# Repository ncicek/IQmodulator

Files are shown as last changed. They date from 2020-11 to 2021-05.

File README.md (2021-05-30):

# IQmodulator

A low cost FPGA-based platform for generating RF signals.
It is implemented with more discrete components than a typical SDR with an "all in one" RF transceiver chip. For example the quadrature double-balanced mixer uses hand-wound trifilar transformers.
 As such, it is intended as a learning platform to show the individual components at play.

# Description
The board is designed to plug into the Lattice MachXO3 FPGA starter board.
The FPGA generates the 10-bit baseband I and Q signals. A MAX5853 DAC generates the baseband analog signals which are filtered with a differential 7th order chebyshev. The FPGA PLL is also used to synthesize the quadrature LO which goes to the quadrature mixer in order to upconvert the baseband up to high frequency.

The RTL uses wishbone modules which are heavily based on material from [Gisselquist Technology's blog posts and sample code](https://zipcpu.com).

# PCB:
Photo of the IQModulator board

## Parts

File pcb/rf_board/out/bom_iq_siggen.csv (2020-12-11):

Comment | Designator | Footprint | LCSC Part Number
3p | C1 | Capacitor_SMD:C_0603_1608Metric
DNI | C12,C13 | Capacitor_SMD:C_0603_1608Metric
0.1u | C16,C17,C18,C19,C20,C21,C30,C38,C41,C42,C43,C44,C48,C49,C51,C52,C53,C54,C55,C56,C57,C58 | Capacitor_SMD:C_0603_1608Metric | C14663
4.7p | C14,C15,C22,C23,C36,C37,C39,C40 | Capacitor_SMD:C_0603_1608Metric | C1669
220u 25V tantalum | C28 | Capacitor_Tantalum_SMD:CP_EIA-7343-43_Kemet-X_Pad2.25x2.55mm_HandSolder | C7231
220u tantalum 25V | C31,C33 | Capacitor_Tantalum_SMD:CP_EIA-7343-43_Kemet-X_Pad2.25x2.55mm_HandSolder | C7231
DNI - Feedforward cap | C35 | Capacitor_SMD:C_0805_2012Metric_Pad1.15x1.40mm_HandSolder
10n | C5 | Capacitor_SMD:C_0603_1608Metric | C57112
220u | C6 | Capacitor_Tantalum_SMD:CP_EIA-7343-43_Kemet-X_Pad2.25x2.55mm_HandSolder | C7231
680p | C71,C72,C83,C84 | Capacitor_SMD:C_0603_1608Metric | C30816
330p | C68,C76,C80,C88 | Capacitor_SMD:C_0603_1608Metric | C1664
10u | C2,C3,C4,C7,C8,C9,C24,C25,C26,C27,C29,C32,C34,C59,C60,C61,C62,C63,C64,C65 | Capacitor_SMD:C_0603_1608Metric | C19702
LED | D1,D2,D3,D4 | LED_SMD:LED_0805_2012Metric_Pad1.15x1.40mm_HandSolder | C34499
BAT15-04W | D5,D6,D7,D8 | Package_TO_SOT_SMD:SOT-323_SC-70_Handsoldering
MBRS540T3G | D9,D10,D11 | Diode_SMD:D_SMB_Handsoldering | C14651
Ferrite_Bead_Small | FB1,FB2,FB3,FB4,FB5,FB6,FB7,FB8,FB9 | Inductor_SMD:L_0805_2012Metric_Pad1.05x1.20mm_HandSolder | C19330
J3 - BANK0 | J1 | Connector_PinHeader_2.54mm:PinHeader_2x20_P2.54mm_Vertical
Barrel_Jack | J10 | Connector_BarrelJack:BarrelJack_Horizontal
Conn_Coaxial | J6,J7,J8,J9,J11,J18,J19 | iq_siggen:SMA_Samtec_SMA-J-P-X-ST-EM1_EdgeMount_withSTEP
Conn_01x01_Male | J4,J12,J13,J14,J15,J16,J17 | Connector_PinHeader_2.54mm:PinHeader_1x01_P2.54mm_Vertical
J4 - BANK1 | J2 | Connector_PinHeader_2.54mm:PinHeader_2x20_P2.54mm_Vertical
Conn_01x20_Male | J3 | Connector_PinHeader_2.54mm:PinHeader_1x20_P2.54mm_Vertical
SolderJumper_3_Open | JP1,JP2,JP4,JP5 | iq_siggen:50ohm_solder_jumper
330n | L10,L12,L20,L23,L28,L30,L38,L41 | Inductor_SMD:L_0603_1608Metric | C46859
470n | L14,L17,L32,L35 | Inductor_SMD:L_0603_1608Metric | C21307
33u | L6 | Inductor_SMD:L_Bourns_SRR1260
3.3u | L7 | Inductor_THT:L_Axial_L9.5mm_D4.0mm_P12.70mm_Horizontal_Fastron_SMCC
6.8k - optional output termination | R100 | Resistor_SMD:R_0603_1608Metric
1.985k | R101 | Resistor_SMD:R_0603_1608Metric
22 | R17,R18,R19,R21,R22,R23,R24,R25,R26,R27,R28,R29,R34,R36,R37,R38,R39,R40,R41,R42,R43,R44,R45,R52,R53 | Resistor_SMD:R_0603_1608Metric | C23345
3k | R48,R49,R86 | Resistor_SMD:R_0603_1608Metric | C4211
DNI | R46,R47,R54,R55,R66,R68 | Resistor_SMD:R_0603_1608Metric
220 | R56,R57,R58,R59 | Resistor_SMD:R_0603_1608Metric | C22962
0 | R2,R3,R4,R5,R6,R7,R10,R11,R12,R13,R14,R15,R16,R30,R31,R32,R33,R67,R69 | Resistor_SMD:R_0603_1608Metric | C21189
16.5 | R62,R63,R64 | Resistor_SMD:R_0603_1608Metric | C12054
DNI-50 | R60,R61,R65,R82 | Resistor_SMD:R_0603_1608Metric
499 | R72,R73,R74,R75,R94,R95,R96,R97 | Resistor_SMD:R_0603_1608Metric | C23065
1.5k | R76,R77,R78,R79 | Resistor_SMD:R_0603_1608Metric | C22843
100 | R8,R70,R71 | Resistor_SMD:R_0603_1608Metric | C22775
49.9 | R80,R81,R92,R93,R104,R105 | Resistor_SMD:R_0603_1608Metric | C23185
DNI - 50 | R83 | Resistor_SMD:R_0603_1608Metric
47k | R84,R85 | Resistor_SMD:R_0603_1608Metric | C25819
1k | R87,R98,R99,R102,R103 | Resistor_SMD:R_0603_1608Metric | C21190
24.9 | R88,R89,R90,R91 | Resistor_SMD:R_0603_1608Metric | C22916
SW_Push | SW1,SW2 | Button_Switch_THT:SW_PUSH_6mm_H5mm
Transformer_1P_SS | T1,T2,T3,T4 | iq_siggen:trifilar_wound_toroidal_rf_transformer
TestPoint | TP1,TP4,TP10,TP17,TP18,TP19,TP22,TP23,TP24,TP25,TP30,TP31,TP32,TP33,TP34 | TestPoint:TestPoint_Pad_D1.5mm
TestPoint | TP51,TP52,TP53,TP56,TP57,TP58 | TestPoint:TestPoint_Pad_D1.0mm
AMS1117-3.3 | U1 | Package_TO_SOT_SMD:SOT-223-3_TabPin2 | C6186
TPS72325DBVR | U2 | Package_TO_SOT_SMD:SOT-23-5_HandSoldering | C69932
TLV73325PDBVT | U3 | Package_TO_SOT_SMD:SOT-23-5_HandSoldering
TLV3542IDR | U4,U7 | Package_SO:SOIC-8_3.9x4.9mm_P1.27mm
LM2596S-ADJ | U5 | Package_TO_SOT_SMD:TO-263-5_TabPin3
MAX5853ETL-T | U6 | iq_siggen:qfn_max5853

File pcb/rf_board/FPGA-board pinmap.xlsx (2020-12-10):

Connector | Pin number | Pin name | Net name
J4 | 24 | H15 | A0
J4 | 20 | J15 | A1
J4 | 17 | K15 | A2
J4 | 16 | K16 | A3
J4 | 15 | K14 | A4
J4 | 14 | L16 | A5
J4 | 10 | M16 | A6
J4 | 8 | N16 | A7
J4 | 7 | L14 | A8
J4 | 6 | N14 | A9
J4 | 39 | G14 | B0
J4 | 37 | D14 | B1
J4 | 38 | F14 | B2
J4 | 35 | D16 | B3
J4 | 34 | E14 | B4
J4 | 33 | E16 | B5
J4 | 30 | E15 | B6
J4 | 29 | F16 | B7
J4 | 28 | F15 | B8
J4 | 26 | G15 | B9
J3 | 10 | D10 | DAC_CLK_P
J3 | 9 | E10 | DAC_CLK_N
J3 | 30 | B9 | I_CLK_P
J3 | 27 | A10 | I_CLK_N
J3 | 18 | D8 | Q_CLK_P
J3 | 16 | E9 | Q_CLK_N
J4 | 5 | M14 | ~CW
J4 | 25 | H16 | CLK_EXT_IN
J4 | 19 | H14 | CLK_OUT
J3 | 13 | f9 | LED0
J3 | 15 | e8 | LED1
J3 | 17 | e7 | LED2
J3 | 19 | d7 | LED3
J3 | 5 | F8 | SW0
J3 | 6 | B12 | SW1

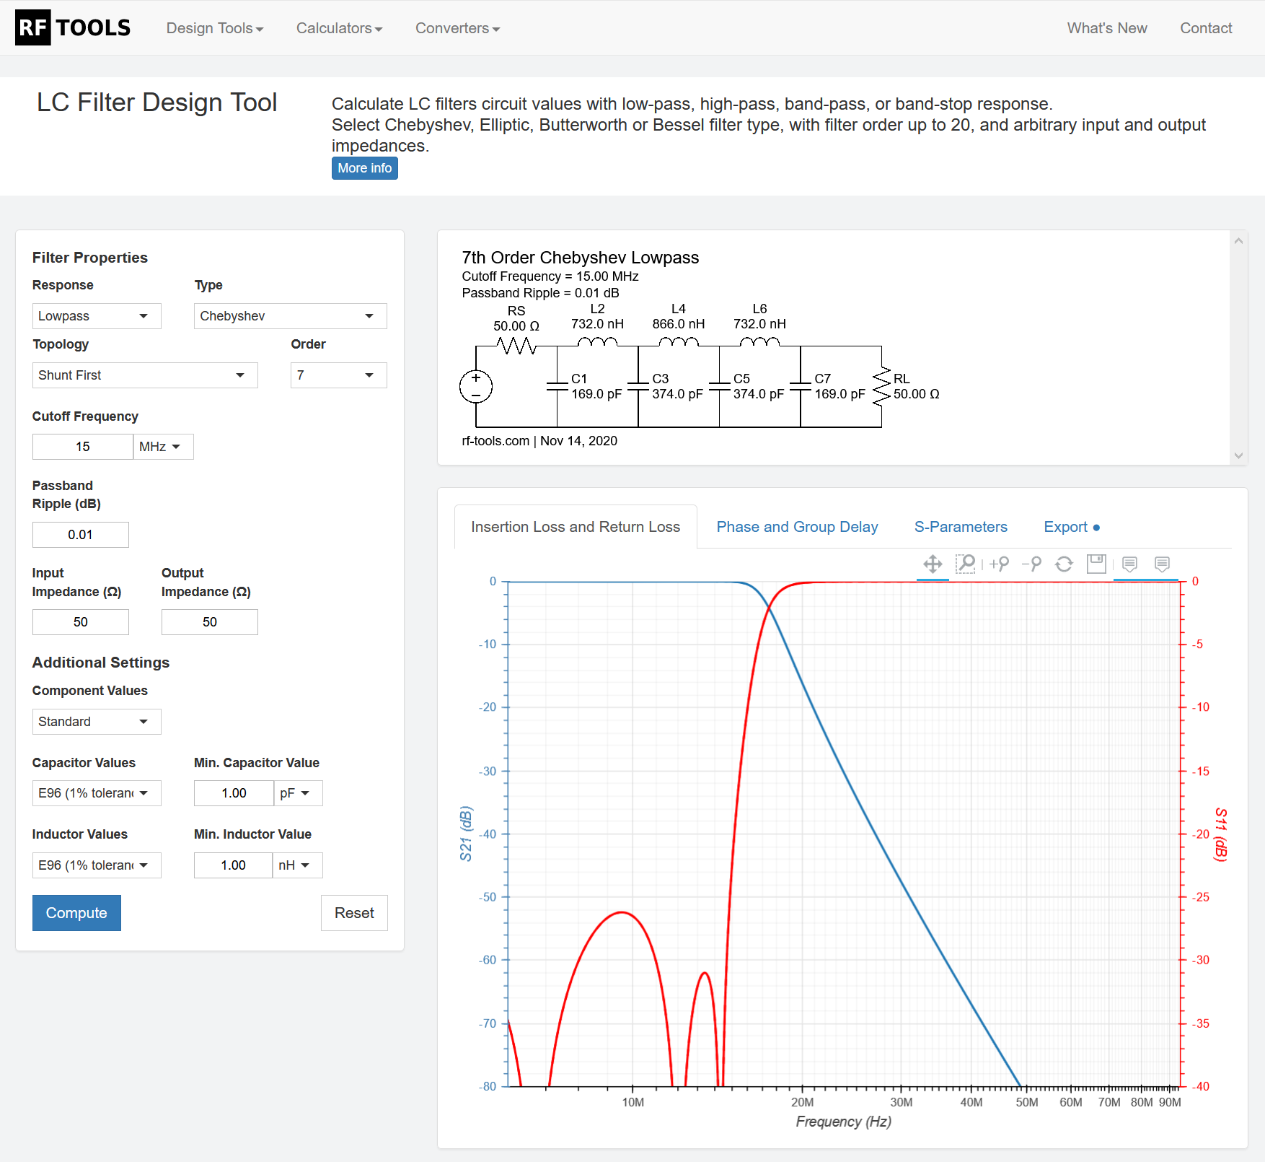
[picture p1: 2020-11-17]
pcb/rf_board/7th order chebyshev 15MHz AA LPF.PNG

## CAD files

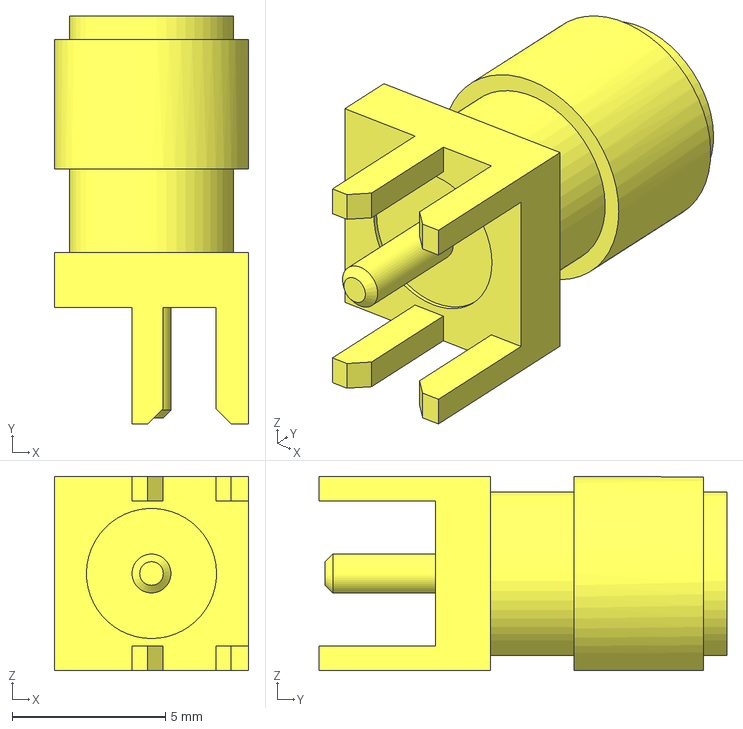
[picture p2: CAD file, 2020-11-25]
pcb/rf_board/SMA-J-P-H-ST-EM1--3DModel-STEP-46669.STEP
6.35 x 13.3 x 6.35 mm

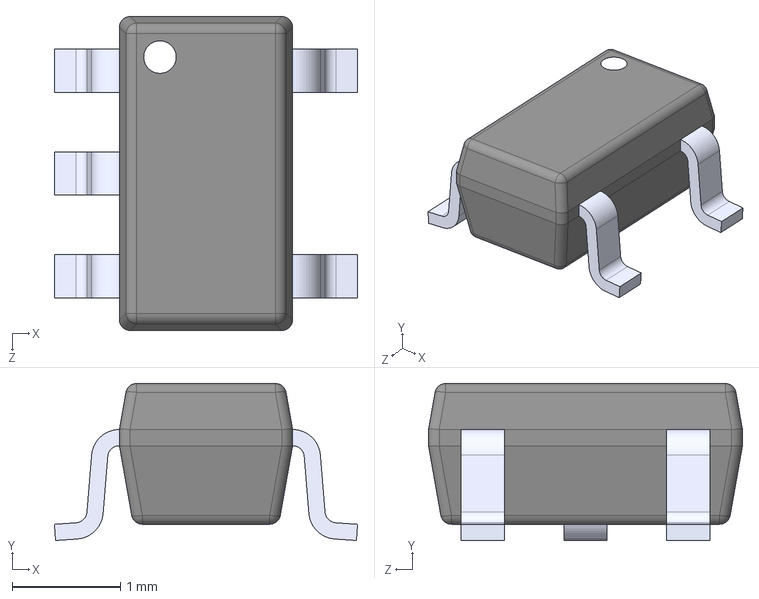
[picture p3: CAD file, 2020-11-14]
pcb/rf_board/TLV73325PDBVT.step
2.80 x 1.45 x 2.90 mm

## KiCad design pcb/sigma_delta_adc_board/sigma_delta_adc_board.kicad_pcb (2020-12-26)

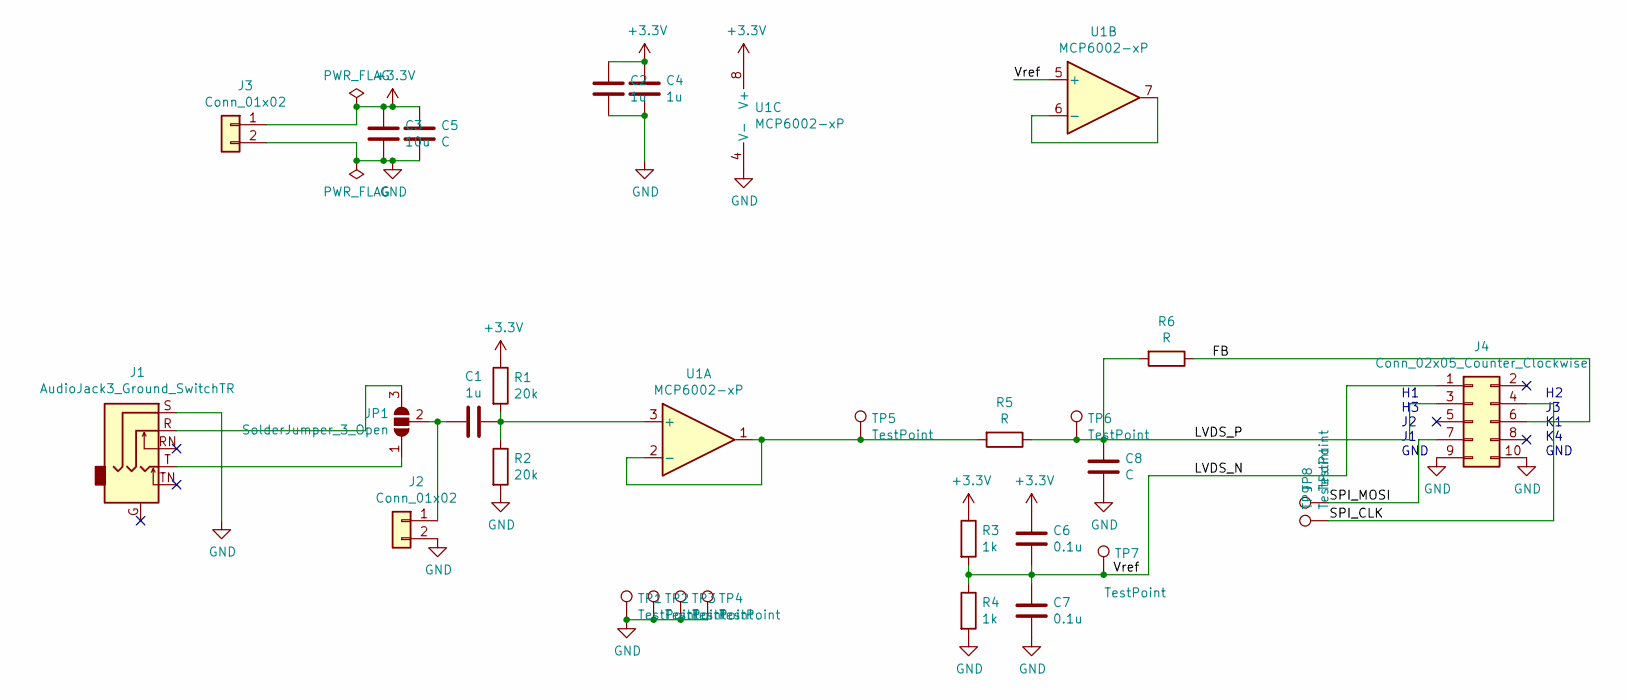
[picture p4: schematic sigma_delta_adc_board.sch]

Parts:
C1: 1u; C_Disc_D5.0mm_W2.5mm_P5.00mm
C2, C4: 1u; C_0805_2012Metric_Pad1.18x1.45mm_HandSolder
C3: 10u; C_Disc_D5.0mm_W2.5mm_P5.00mm
C5: C; C_Disc_D5.0mm_W2.5mm_P5.00mm
C6, C7: 0.1u; C_0805_2012Metric_Pad1.18x1.45mm_HandSolder
C8: C; C_0805_2012Metric_Pad1.18x1.45mm_HandSolder
J1: AudioJack3_Ground_SwitchTR; STX-3120-5B
J2, J3: Conn_01x02; PinHeader_1x02_P2.54mm_Vertical
J4: Conn_02x05_Counter_Clockwise; PinSocket_2x05_P2.54mm_Vertical
JP1: SolderJumper_3_Open; SolderJumper-3_P1.3mm_Open_RoundedPad1.0x1.5mm_NumberLabels
R1, R2: 20k; R_0805_2012Metric_Pad1.20x1.40mm_HandSolder
R3, R4: 1k; R_0805_2012Metric_Pad1.20x1.40mm_HandSolder
R5, R6: R; R_0805_2012Metric_Pad1.20x1.40mm_HandSolder
TP1, TP2, TP3, TP4, TP5, TP6, TP7: TestPoint; PinHeader_1x01_P2.54mm_Vertical
TP8, TP9: TestPoint; TestPoint_Pad_D1.0mm
U1: MCP6002-xP; DIP-8_W7.62mm

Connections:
+3V3: C2.2, C3.1, C4.2, C5.1, C6.2, J3.1, R1.1, R3.1, U1.8 (V+)
/FB: J4.6, R6.1
/LVDS_N: C6.1, C7.2, J4.1, R3.2, R4.1, TP7.1, U1.5 (+)
/LVDS_P: C8.2, J4.3, R5.1, R6.2, TP6.1
/SPI_CLK: J4.4, TP9.1
/SPI_MOSI: J4.7, TP8.1
GND: C2.1, C3.2, C4.1, C5.2, C7.1, C8.1, J1.S, J2.2, J3.2, J4.9, J4.10, R2.2, R4.2, TP1.1, TP2.1, TP3.1, TP4.1, U1.4 (V-)
unnamed: C1.1, R1.2, R2.1, U1.3 (+)
unnamed: C1.2, J2.1, JP1.2 (C)
unnamed: J1.R, JP1.3 (B)
unnamed: J1.T, JP1.1 (A)
unnamed: R5.2, TP5.1, U1.1, U1.2 (-)
unnamed: U1.6 (-), U1.7

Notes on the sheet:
H1 H3 J2 J1 GND
H2 J3 K1 K4 GND

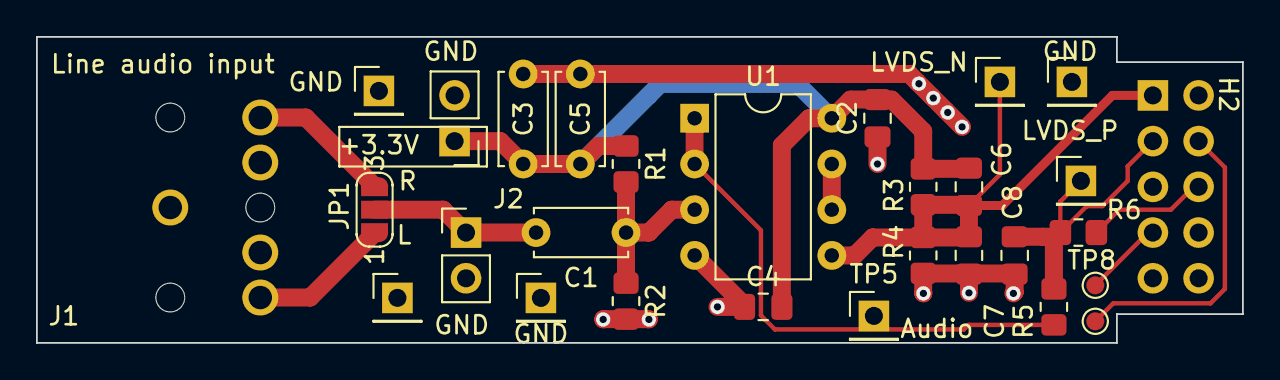
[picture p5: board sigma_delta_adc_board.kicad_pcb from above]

Board: 2 copper layers, 67.0 x 17.0 mm, 29 parts (1 on the bottom side), 13 nets.

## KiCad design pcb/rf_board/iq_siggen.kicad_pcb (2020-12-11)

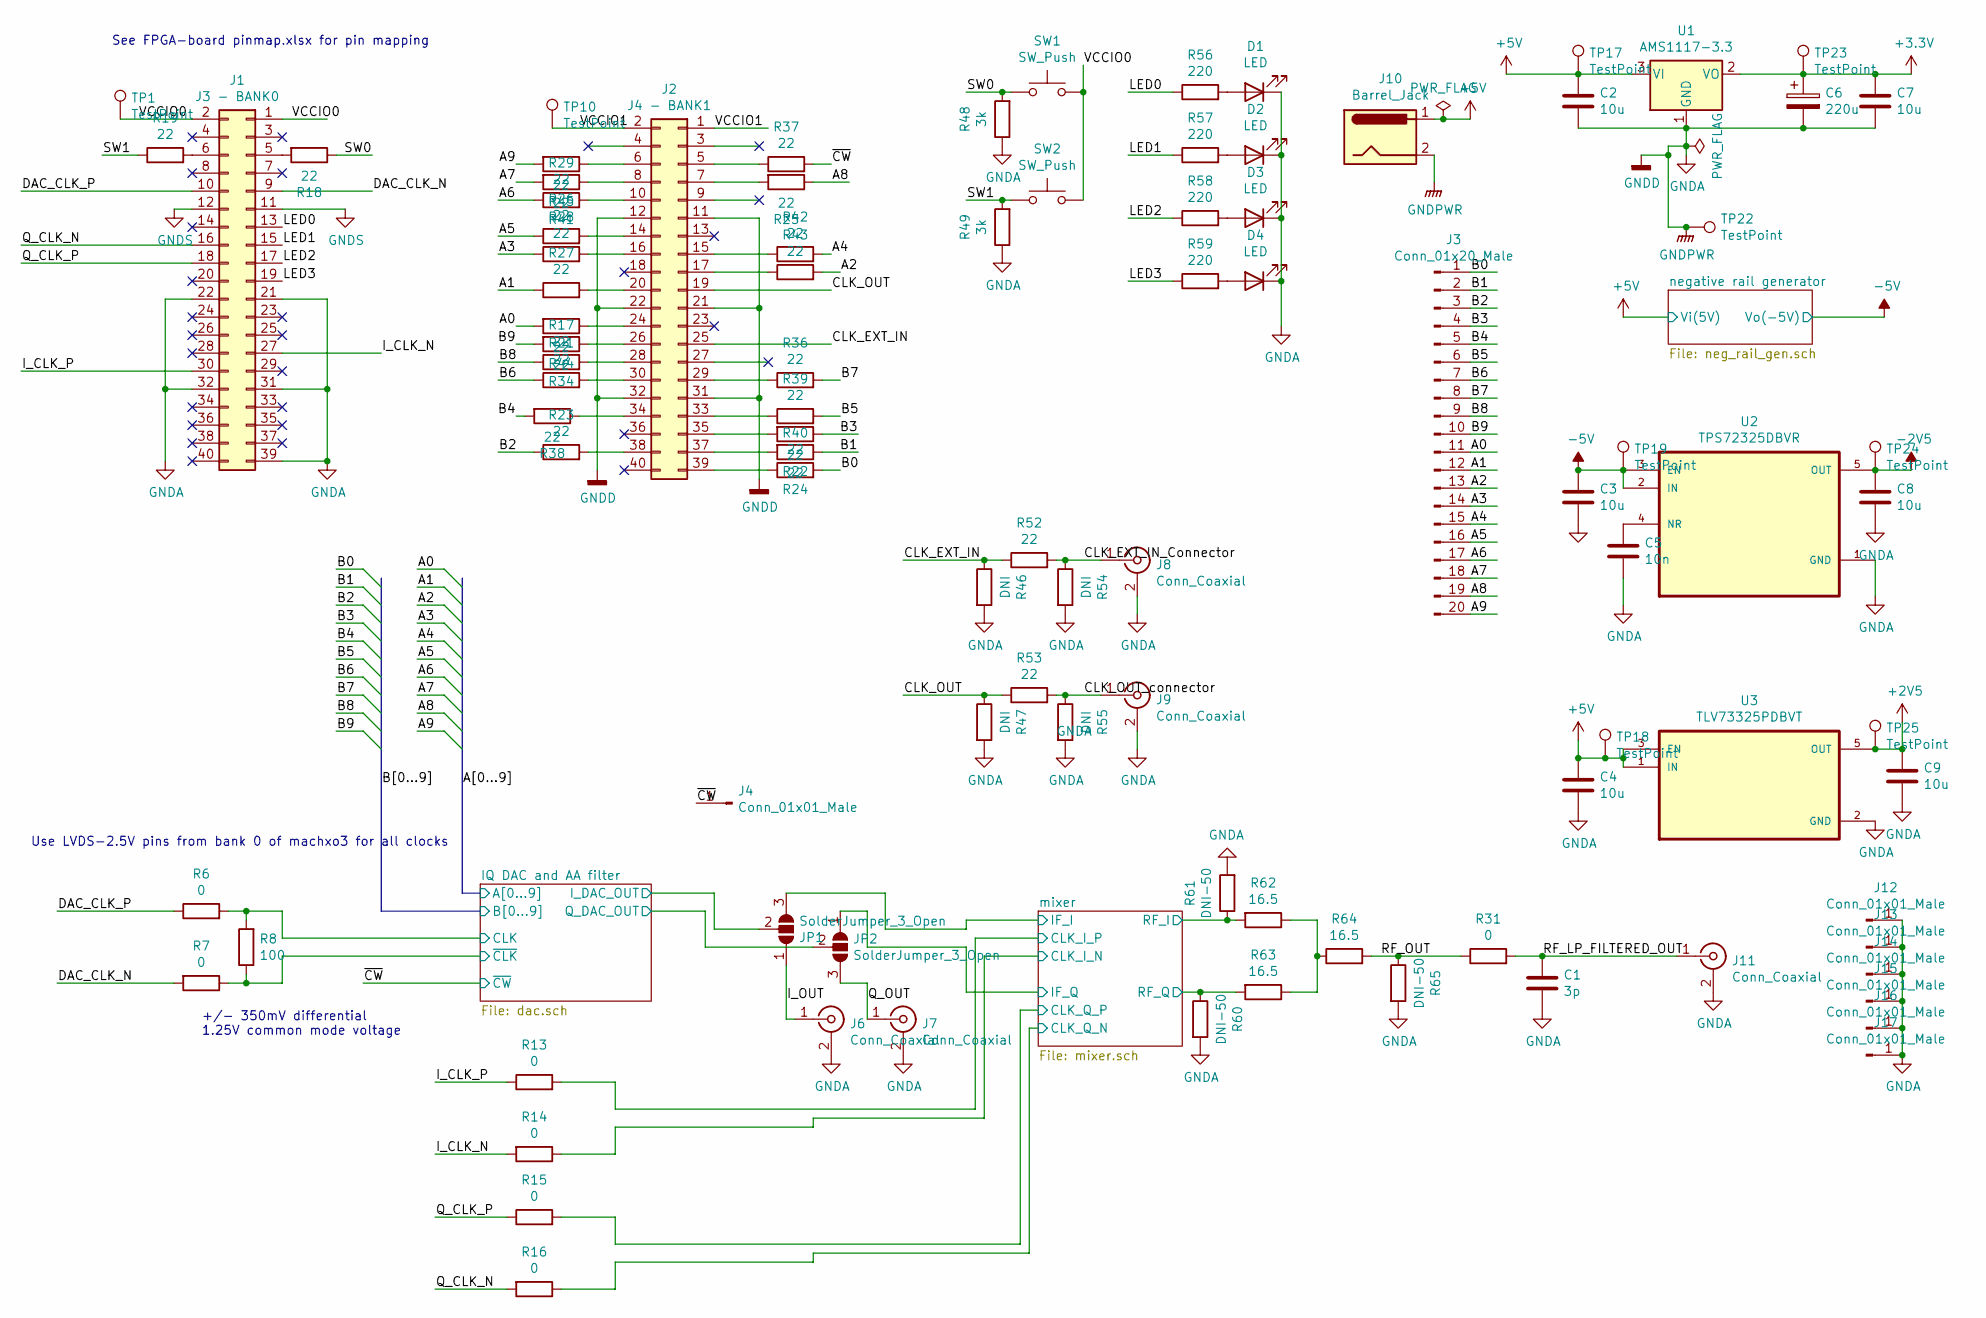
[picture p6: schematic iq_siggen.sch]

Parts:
C1: 3p; C_0603_1608Metric
C2, C3, C4, C7, C8, C9: 10u; C_0603_1608Metric; LCSC C19702
C5: 10n; C_0603_1608Metric; LCSC C57112
C6: 220u; CP_EIA-7343-43_Kemet-X_Pad2.25x2.55mm_HandSolder; LCSC C7231
D1, D2, D3, D4: LED; LED_0805_2012Metric_Pad1.15x1.40mm_HandSolder; LCSC C34499
J1: J3 - BANK0; PinHeader_2x20_P2.54mm_Vertical
J2: J4 - BANK1; PinHeader_2x20_P2.54mm_Vertical
J3: Conn_01x20_Male; PinHeader_1x20_P2.54mm_Vertical
J4, J12, J13, J14, J15, J16, J17: Conn_01x01_Male; PinHeader_1x01_P2.54mm_Vertical
J6, J7, J8, J9, J11: Conn_Coaxial; SMA_Samtec_SMA-J-P-X-ST-EM1_EdgeMount_withSTEP
J10: Barrel_Jack; BarrelJack_Horizontal
JP1, JP2: SolderJumper_3_Open; 50ohm_solder_jumper
R6, R7, R13, R14, R15, R16, R31: 0; R_0603_1608Metric; LCSC C21189
R8: 100; R_0603_1608Metric; LCSC C22775
R17, R18, R19, R21, R22, R23, R24, R25, R26, R27, R28, R29, R34, R36, R37, R38, R39, R40, R41, R42, R43, R44, R45, R52, R53: 22; R_0603_1608Metric; LCSC C23345
R46, R47, R54, R55: DNI; R_0603_1608Metric
R48, R49: 3k; R_0603_1608Metric; LCSC C4211
R56, R57, R58, R59: 220; R_0603_1608Metric; LCSC C22962
R60, R61, R65: DNI-50; R_0603_1608Metric
R62, R63, R64: 16.5; R_0603_1608Metric; LCSC C12054
SW1, SW2: SW_Push; SW_PUSH_6mm_H5mm
TP1, TP10, TP17, TP18, TP19, TP22, TP23, TP24, TP25: TestPoint; TestPoint_Pad_D1.5mm
U1: AMS1117-3.3; SOT-223-3_TabPin2; LCSC C6186
U2: TPS72325DBVR; SOT-23-5_HandSoldering; LCSC C69932
U3: TLV73325PDBVT; SOT-23-5_HandSoldering

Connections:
+2V5: C9.1, TP25.1, U3.5 (OUT); also elsewhere on the board
+3V3: C6.1, C7.1, TP23.1, U1.2 (VO); also elsewhere on the board
+5V: C2.1, C4.1, J10.1, TP17.1, TP18.1, U1.3 (VI), U3.1 (IN), U3.3 (EN); also elsewhere on the board
-2V5: C8.1, TP24.1, U2.5 (OUT); also elsewhere on the board
-5V: C3.1, TP19.1, U2.2 (IN), U2.3 (EN); also elsewhere on the board
/A0: J3.11, R44.2; also elsewhere on the board
/A1: J3.12, R27.1; also elsewhere on the board
/A2: J3.13, R43.2; also elsewhere on the board
/A3: J3.14, R28.1; also elsewhere on the board
/A4: J3.15, R42.2; also elsewhere on the board
/A5: J3.16, R26.1; also elsewhere on the board
/A6: J3.17, R29.1; also elsewhere on the board
/A7: J3.18, R41.2; also elsewhere on the board
/A8: J3.19, R25.1; also elsewhere on the board
/A9: J3.20, R45.2; also elsewhere on the board
/B0: J3.1, R40.2; also elsewhere on the board
/B1: J3.2, R24.1; also elsewhere on the board
/B2: J3.3, R23.1; also elsewhere on the board
/B3: J3.4, R22.1; also elsewhere on the board
/B4: J3.5, R38.2; also elsewhere on the board
/B5: J3.6, R39.2; also elsewhere on the board
/B6: J3.7, R21.1; also elsewhere on the board
/B7: J3.8, R36.2; also elsewhere on the board
/B8: J3.9, R17.1; also elsewhere on the board
/B9: J3.10, R34.2; also elsewhere on the board
/CLK_EXT_IN: J2.25, R46.1, R52.1
/CLK_EXT_IN_Connector: J8.1 (In), R52.2, R54.1
/CLK_OUT: J2.19, R47.1, R53.1
/CLK_OUT_connector: J9.1 (In), R53.2, R55.1
/DAC_CLK_N: J1.9, R7.2
/DAC_CLK_P: J1.10, R6.1
/IQ DAC and AA filter/CLK: R6.2, R8.2; also elsewhere on the board
/IQ DAC and AA filter/I_DAC_OUT: JP1.2 (C); also elsewhere on the board
/IQ DAC and AA filter/Q_DAC_OUT: JP2.2 (C); also elsewhere on the board
/IQ DAC and AA filter/~CLK: R7.1, R8.1; also elsewhere on the board
/I_CLK_N: J1.27, R14.2
/I_CLK_P: J1.30, R13.1
/I_OUT: J6.1 (In), JP1.1 (A)
/LED0: J1.13, R56.1
/LED1: J1.15, R57.1
/LED2: J1.17, R58.1
/LED3: J1.19, R59.1
/Q_CLK_N: J1.16, R16.2
/Q_CLK_P: J1.18, R15.1
/Q_OUT: J7.1 (In), JP2.3 (B)
/RF_LP_FILTERED_OUT: C1.1, J11.1 (In), R31.2
/RF_OUT: R31.1, R64.2, R65.1
/SW0: R18.1, R48.2, SW1.1
/SW1: R19.1, R49.2, SW2.1
/VCCIO0: J1.1, J1.2, SW1.2, SW2.2, TP1.1
/VCCIO1: J2.1, J2.2, TP10.1
/mixer/CLK_I_N: R14.1; also elsewhere on the board
/mixer/CLK_I_P: R13.2; also elsewhere on the board
/mixer/CLK_Q_N: R16.1; also elsewhere on the board
/mixer/CLK_Q_P: R15.2; also elsewhere on the board
/mixer/IF_I: JP1.3 (B); also elsewhere on the board
/mixer/IF_Q: JP2.1 (A); also elsewhere on the board
/mixer/RF_I: R61.1, R62.2; also elsewhere on the board
/mixer/RF_Q: R60.1, R63.2; also elsewhere on the board
/~CW: J4.1, R37.2; also elsewhere on the board
GNDA: C1.2, C2.2, C3.2, C4.2, C5.2, C6.2, C7.2, C8.2, C9.2, D1.1 (K), D2.1 (K), D3.1 (K), D4.1 (K), J1.11, J1.12, J1.21, J1.22, J1.31, J1.32, J1.39, J2.11, J2.12, J2.21, J2.22, J2.31, J2.32, J6.2 (Ext), J7.2 (Ext), J8.2 (Ext), J9.2 (Ext), J10.2, J11.2 (Ext), J12.1, J13.1, J14.1, J15.1, J16.1, J17.1, R46.2, R47.2, R48.1, R49.1, R54.2, R55.2, R60.2, R61.2, R65.2, TP22.1, U1.1 (GND), U2.1 (GND), U3.2 (GND); also elsewhere on the board
unnamed: C5.1, U2.4 (NR)
unnamed: D1.2 (A), R56.2
unnamed: D2.2 (A), R57.2
unnamed: D3.2 (A), R58.2
unnamed: D4.2 (A), R59.2
unnamed: J1.5, R18.2
unnamed: J1.6, R19.2
unnamed: J2.5, R37.1
unnamed: J2.6, R45.1
unnamed: J2.7, R25.2
unnamed: J2.8, R41.1
unnamed: J2.10, R29.2
unnamed: J2.14, R26.2
unnamed: J2.15, R42.1
unnamed: J2.16, R28.2
unnamed: J2.17, R43.1
unnamed: J2.20, R27.2
unnamed: J2.24, R44.1
unnamed: J2.26, R34.1
unnamed: J2.28, R17.2
unnamed: J2.29, R36.1
unnamed: J2.30, R21.2
unnamed: J2.33, R39.1
unnamed: J2.34, R38.1
unnamed: J2.35, R22.2
unnamed: J2.37, R24.2
unnamed: J2.38, R23.2
unnamed: J2.39, R40.1
unnamed: R62.1, R63.1, R64.1

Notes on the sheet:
Use LVDS-2.5V pins from bank 0 of machxo3 for all clocks
See FPGA-board pinmap.xlsx for pin mapping
+/- 350mV differential 1.25V common mode voltage

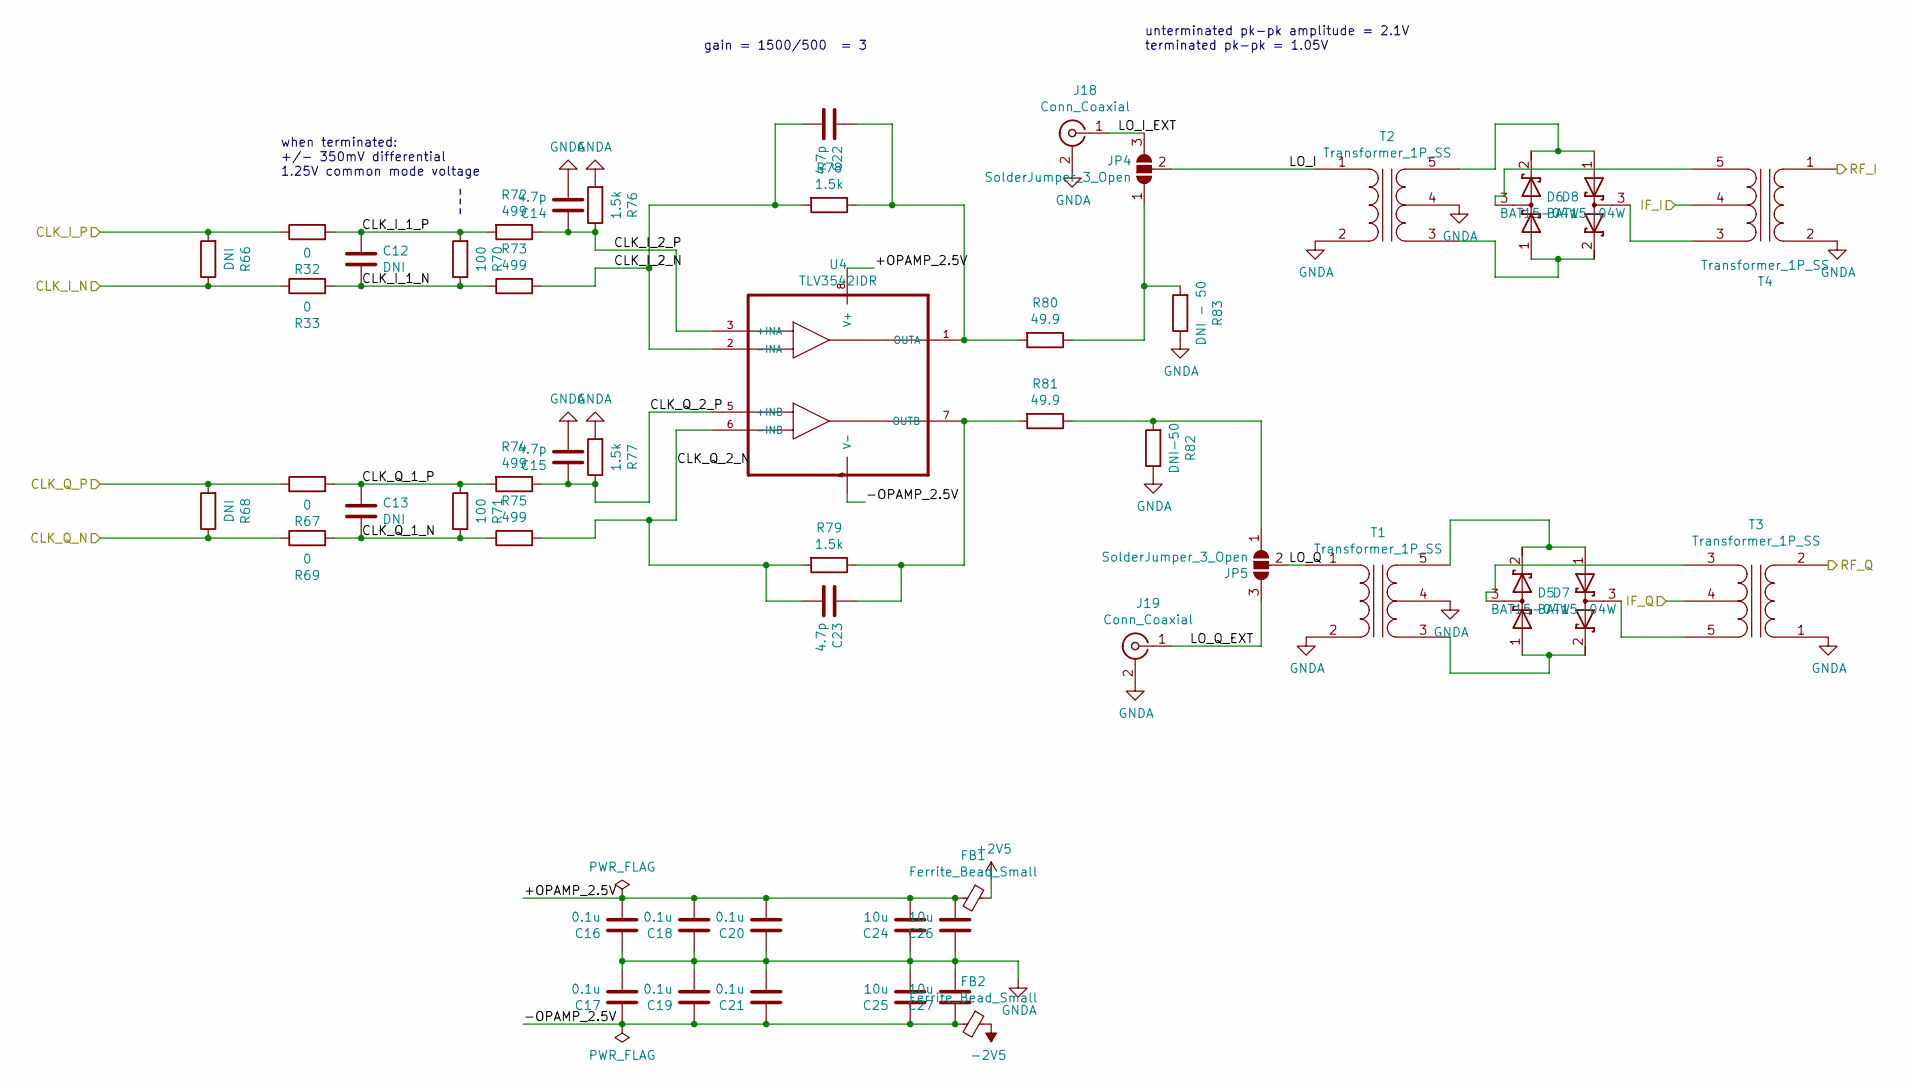
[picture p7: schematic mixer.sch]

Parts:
C12, C13: DNI; C_0603_1608Metric
C14, C15, C22, C23: 4.7p; C_0603_1608Metric; LCSC C1669
C16, C17, C18, C19, C20, C21: 0.1u; C_0603_1608Metric; LCSC C14663
C24, C25, C26, C27: 10u; C_0603_1608Metric; LCSC C19702
D5, D6, D7, D8: BAT15-04W; SOT-323_SC-70_Handsoldering
FB1, FB2: Ferrite_Bead_Small; L_0805_2012Metric_Pad1.05x1.20mm_HandSolder; LCSC C19330
J18, J19: Conn_Coaxial; SMA_Samtec_SMA-J-P-X-ST-EM1_EdgeMount_withSTEP
JP4, JP5: SolderJumper_3_Open; 50ohm_solder_jumper
R32, R33, R67, R69: 0; R_0603_1608Metric; LCSC C21189
R66, R68: DNI; R_0603_1608Metric
R70, R71: 100; R_0603_1608Metric; LCSC C22775
R72, R73, R74, R75: 499; R_0603_1608Metric; LCSC C23065
R76, R77, R78, R79: 1.5k; R_0603_1608Metric; LCSC C22843
R80, R81: 49.9; R_0603_1608Metric; LCSC C23185
R82: DNI-50; R_0603_1608Metric
R83: DNI - 50; R_0603_1608Metric
T1, T2, T3, T4: Transformer_1P_SS; trifilar_wound_toroidal_rf_transformer
U4: TLV3542IDR; SOIC-8_3.9x4.9mm_P1.27mm

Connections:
+2V5: FB1.1; also elsewhere on the board
-2V5: FB2.1; also elsewhere on the board
/mixer/+OPAMP_2.5V: C16.2, C18.2, C20.2, C24.2, C26.2, FB1.2, U4.8 (V+)
/mixer/-OPAMP_2.5V: C17.1, C19.1, C21.1, C25.1, C27.1, FB2.2, U4.4 (V-)
/mixer/CLK_I_1_N: C12.2, R33.2, R70.1, R73.1
/mixer/CLK_I_1_P: C12.1, R32.2, R70.2, R72.2
/mixer/CLK_I_2_N: C22.2, R73.2, R78.2, U4.2 (-INA)
/mixer/CLK_I_2_P: C14.1, R72.1, R76.1, U4.3 (+INA)
/mixer/CLK_I_N: R33.1, R66.1; also elsewhere on the board
/mixer/CLK_I_P: R32.1, R66.2; also elsewhere on the board
/mixer/CLK_Q_1_N: C13.2, R69.2, R71.1, R75.1
/mixer/CLK_Q_1_P: C13.1, R67.2, R71.2, R74.2
/mixer/CLK_Q_2_N: C23.2, R75.2, R79.2, U4.6 (-INB)
/mixer/CLK_Q_2_P: C15.1, R74.1, R77.1, U4.5 (+INB)
/mixer/CLK_Q_N: R68.1, R69.1; also elsewhere on the board
/mixer/CLK_Q_P: R67.1, R68.2; also elsewhere on the board
/mixer/IF_I: T4.4 (SC); also elsewhere on the board
/mixer/IF_Q: T3.4 (SC); also elsewhere on the board
/mixer/LO_I: JP4.2 (C), T2.1 (AA)
/mixer/LO_I_EXT: J18.1 (In), JP4.3 (B)
/mixer/LO_Q: JP5.2 (C), T1.1 (AA)
/mixer/LO_Q_EXT: J19.1 (In), JP5.3 (B)
/mixer/RF_I: T4.1 (AA); also elsewhere on the board
/mixer/RF_Q: T3.2 (AB); also elsewhere on the board
GNDA: C14.2, C15.2, C16.1, C17.2, C18.1, C19.2, C20.1, C21.2, C24.1, C25.2, C26.1, C27.2, J18.2 (Ext), J19.2 (Ext), R76.2, R77.2, R82.1, R83.1, T1.2 (AB), T1.4 (SC), T2.2 (AB), T2.4 (SC), T3.1 (AA), T4.2 (AB); also elsewhere on the board
unnamed: C22.1, R78.1, R80.2, U4.1 (OUTA)
unnamed: C23.1, R79.1, R81.2, U4.7 (OUTB)
unnamed: D5.1 (A), D7.2 (K), T1.3 (SA)
unnamed: D5.2 (K), D7.1 (A), T1.5 (SB)
unnamed: D5.3 (common), T3.3 (SA)
unnamed: D6.1 (A), D8.2 (K), T2.3 (SA)
unnamed: D6.2 (K), D8.1 (A), T2.5 (SB)
unnamed: D6.3 (common), T4.5 (SB)
unnamed: D7.3 (common), T3.5 (SB)
unnamed: D8.3 (common), T4.3 (SA)
unnamed: JP4.1 (A), R80.1, R83.2
unnamed: JP5.1 (A), R81.1, R82.2

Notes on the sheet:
when terminated: +/- 350mV differential 1.25V common mode voltage
gain = 1500/500 = 3
unterminated pk-pk amplitude = 2.1V terminated pk-pk = 1.05V

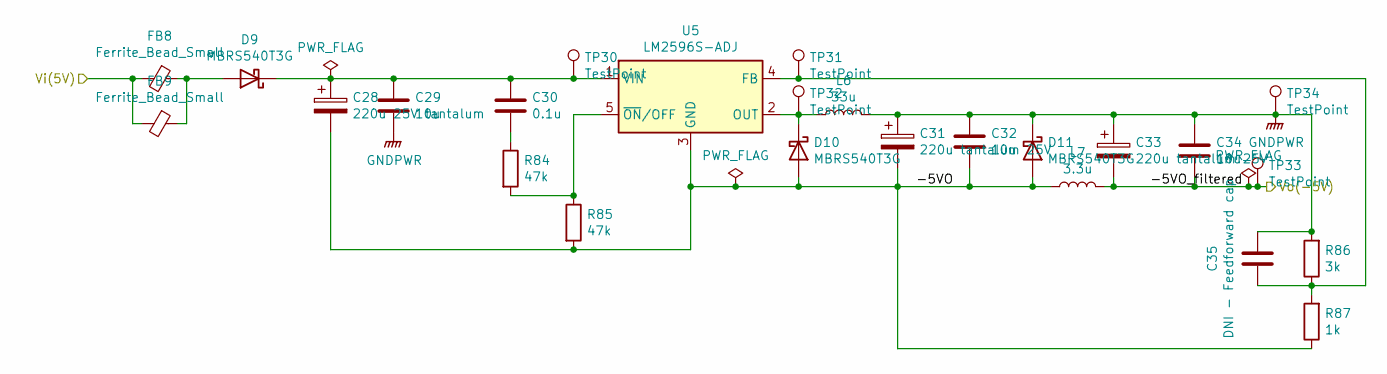
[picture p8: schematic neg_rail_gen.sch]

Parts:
C28: 220u 25V tantalum; CP_EIA-7343-43_Kemet-X_Pad2.25x2.55mm_HandSolder; LCSC C7231
C29, C32, C34: 10u; C_0603_1608Metric; LCSC C19702
C30: 0.1u; C_0603_1608Metric; LCSC C14663
C31, C33: 220u tantalum 25V; CP_EIA-7343-43_Kemet-X_Pad2.25x2.55mm_HandSolder; LCSC C7231
C35: DNI - Feedforward cap; C_0805_2012Metric_Pad1.15x1.40mm_HandSolder
D9, D10, D11: MBRS540T3G; D_SMB_Handsoldering; LCSC C14651
FB8, FB9: Ferrite_Bead_Small; L_0805_2012Metric_Pad1.05x1.20mm_HandSolder; LCSC C19330
L6: 33u; L_Bourns_SRR1260
L7: 3.3u; L_Axial_L9.5mm_D4.0mm_P12.70mm_Horizontal_Fastron_SMCC
R84, R85: 47k; R_0603_1608Metric; LCSC C25819
R86: 3k; R_0603_1608Metric; LCSC C4211
R87: 1k; R_0603_1608Metric; LCSC C21190
TP30, TP31, TP32, TP33, TP34: TestPoint; TestPoint_Pad_D1.5mm
U5: LM2596S-ADJ; TO-263-5_TabPin3

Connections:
+5V: FB8.2, FB9.2; also elsewhere on the board
-5V: C33.2, C34.1, L7.2, TP33.1; also elsewhere on the board
/negative rail generator/-5VO: C28.2, C31.2, C32.1, D10.2 (A), D11.2 (A), L7.1, R85.2, R87.1, U5.3 (GND)
GNDA: C29.2, C31.1, C32.2, C33.1, C34.2, C35.2, D11.1 (K), L6.2, R86.2, TP34.1; also elsewhere on the board
unnamed: C28.1, C29.1, C30.1, D9.1 (K), TP30.1, U5.1 (VIN)
unnamed: C30.2, R84.1
unnamed: C35.1, R86.1, R87.2, TP31.1, U5.4 (FB)
unnamed: D9.2 (A), FB8.1, FB9.1
unnamed: D10.1 (K), L6.1, TP32.1, U5.2 (OUT)
unnamed: R84.2, R85.1, U5.5 (~ON~/OFF)

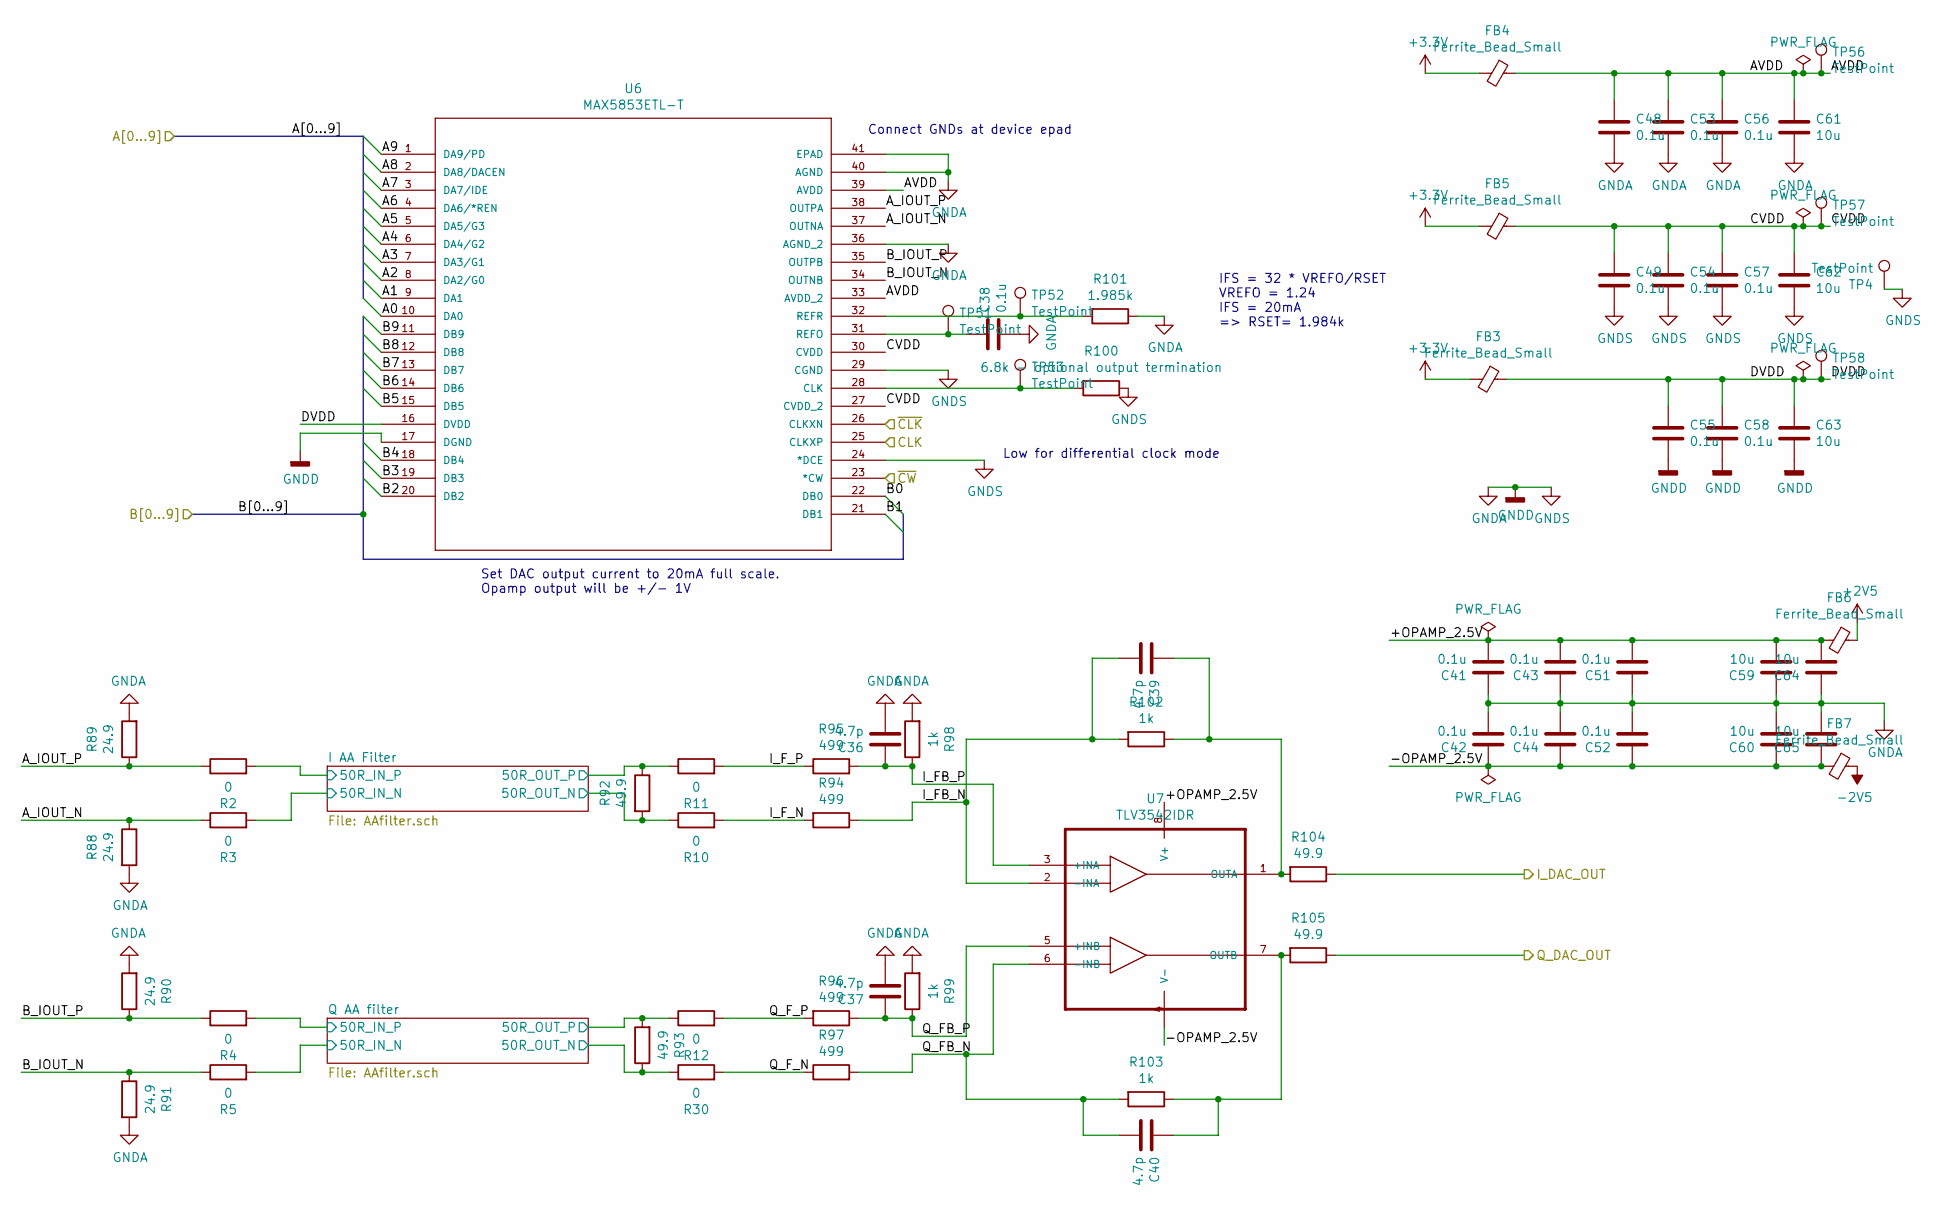
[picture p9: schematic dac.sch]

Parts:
C36, C37, C39, C40: 4.7p; C_0603_1608Metric; LCSC C1669
C38, C41, C42, C43, C44, C48, C49, C51, C52, C53, C54, C55, C56, C57, C58: 0.1u; C_0603_1608Metric; LCSC C14663
C59, C60, C61, C62, C63, C64, C65: 10u; C_0603_1608Metric; LCSC C19702
FB3, FB4, FB5, FB6, FB7: Ferrite_Bead_Small; L_0805_2012Metric_Pad1.05x1.20mm_HandSolder; LCSC C19330
R2, R3, R4, R5, R10, R11, R12, R30: 0; R_0603_1608Metric; LCSC C21189
R88, R89, R90, R91: 24.9; R_0603_1608Metric; LCSC C22916
R92, R93, R104, R105: 49.9; R_0603_1608Metric; LCSC C23185
R94, R95, R96, R97: 499; R_0603_1608Metric; LCSC C23065
R98, R99, R102, R103: 1k; R_0603_1608Metric; LCSC C21190
R100: 6.8k - optional output termination; R_0603_1608Metric
R101: 1.985k; R_0603_1608Metric
TP4: TestPoint; TestPoint_Pad_D1.5mm
TP51, TP52, TP53, TP56, TP57, TP58: TestPoint; TestPoint_Pad_D1.0mm
U6: MAX5853ETL-T; qfn_max5853
U7: TLV3542IDR; SOIC-8_3.9x4.9mm_P1.27mm

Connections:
+2V5: FB6.1; also elsewhere on the board
+3V3: FB3.2, FB4.2, FB5.2; also elsewhere on the board
-2V5: FB7.1; also elsewhere on the board
/A0: U6.10 (DA0); also elsewhere on the board
/A1: U6.9 (DA1); also elsewhere on the board
/A2: U6.8 (DA2/G0); also elsewhere on the board
/A3: U6.7 (DA3/G1); also elsewhere on the board
/A4: U6.6 (DA4/G2); also elsewhere on the board
/A5: U6.5 (DA5/G3); also elsewhere on the board
/A6: U6.4 (DA6/*REN); also elsewhere on the board
/A7: U6.3 (DA7/IDE); also elsewhere on the board
/A8: U6.2 (DA8/DACEN); also elsewhere on the board
/A9: U6.1 (DA9/PD); also elsewhere on the board
/B0: U6.22 (DB0); also elsewhere on the board
/B1: U6.21 (DB1); also elsewhere on the board
/B2: U6.20 (DB2); also elsewhere on the board
/B3: U6.19 (DB3); also elsewhere on the board
/B4: U6.18 (DB4); also elsewhere on the board
/B5: U6.15 (DB5); also elsewhere on the board
/B6: U6.14 (DB6); also elsewhere on the board
/B7: U6.13 (DB7); also elsewhere on the board
/B8: U6.12 (DB8); also elsewhere on the board
/B9: U6.11 (DB9); also elsewhere on the board
/IQ DAC and AA filter/+OPAMP_2.5V: C41.2, C43.2, C51.2, C59.2, C64.2, FB6.2, U7.8 (V+)
/IQ DAC and AA filter/-OPAMP_2.5V: C42.1, C44.1, C52.1, C60.1, C65.1, FB7.2, U7.4 (V-)
/IQ DAC and AA filter/AVDD: C48.1, C53.1, C56.1, C61.1, FB4.1, TP56.1, U6.33 (AVDD_2), U6.39 (AVDD)
/IQ DAC and AA filter/A_IOUT_N: R3.1, R88.1, U6.37 (OUTNA)
/IQ DAC and AA filter/A_IOUT_P: R2.1, R89.1, U6.38 (OUTPA)
/IQ DAC and AA filter/B_IOUT_N: R5.1, R91.1, U6.34 (OUTNB)
/IQ DAC and AA filter/B_IOUT_P: R4.1, R90.1, U6.35 (OUTPB)
/IQ DAC and AA filter/CLK: U6.25 (CLKXP); also elsewhere on the board
/IQ DAC and AA filter/CVDD: C49.1, C54.1, C57.1, C62.1, FB5.1, TP57.1, U6.27 (CVDD_2), U6.30 (CVDD)
/IQ DAC and AA filter/DVDD: C55.1, C58.1, C63.1, FB3.1, TP58.1, U6.16 (DVDD)
/IQ DAC and AA filter/I AA Filter/50R_IN_N: R3.2; also elsewhere on the board
/IQ DAC and AA filter/I AA Filter/50R_IN_P: R2.2; also elsewhere on the board
/IQ DAC and AA filter/I AA Filter/50R_OUT_N: R10.1, R92.2; also elsewhere on the board
/IQ DAC and AA filter/I AA Filter/50R_OUT_P: R11.1, R92.1; also elsewhere on the board
/IQ DAC and AA filter/I_DAC_OUT: R104.1; also elsewhere on the board
/IQ DAC and AA filter/I_FB_N: C39.2, R94.1, R102.2, U7.2 (-INA)
/IQ DAC and AA filter/I_FB_P: C36.1, R95.2, R98.1, U7.3 (+INA)
/IQ DAC and AA filter/I_F_N: R10.2, R94.2
/IQ DAC and AA filter/I_F_P: R11.2, R95.1
/IQ DAC and AA filter/Q AA filter/50R_IN_N: R5.2; also elsewhere on the board
/IQ DAC and AA filter/Q AA filter/50R_IN_P: R4.2; also elsewhere on the board
/IQ DAC and AA filter/Q AA filter/50R_OUT_N: R30.1, R93.1; also elsewhere on the board
/IQ DAC and AA filter/Q AA filter/50R_OUT_P: R12.1, R93.2; also elsewhere on the board
/IQ DAC and AA filter/Q_DAC_OUT: R105.1; also elsewhere on the board
/IQ DAC and AA filter/Q_FB_N: C40.2, R97.2, R103.2, U7.6 (-INB)
/IQ DAC and AA filter/Q_FB_P: C37.1, R96.1, R99.1, U7.5 (+INB)
/IQ DAC and AA filter/Q_F_N: R30.2, R97.1
/IQ DAC and AA filter/Q_F_P: R12.2, R96.2
/IQ DAC and AA filter/~CLK: U6.26 (CLKXN); also elsewhere on the board
/~CW: U6.23 (*CW); also elsewhere on the board
GNDA: C36.2, C37.2, C38.2, C41.1, C42.2, C43.1, C44.2, C48.2, C49.2, C51.1, C52.2, C53.2, C54.2, C55.2, C56.2, C57.2, C58.2, C59.1, C60.2, C61.2, C62.2, C63.2, C64.1, C65.2, R88.2, R89.2, R90.2, R91.2, R98.2, R99.2, R100.1, R101.1, TP4.1, U6.17 (DGND), U6.24 (*DCE), U6.29 (CGND), U6.36 (AGND_2), U6.40 (AGND), U6.41 (EPAD); also elsewhere on the board
unnamed: C38.1, TP51.1, U6.31 (REFO)
unnamed: C39.1, R102.1, R104.2, U7.1 (OUTA)
unnamed: C40.1, R103.1, R105.2, U7.7 (OUTB)
unnamed: R100.2, TP53.1, U6.28 (CLK)
unnamed: R101.2, TP52.1, U6.32 (REFR)

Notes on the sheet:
Connect GNDs at device epad
Set DAC output current to 20mA full scale. Opamp output will be +/- 1V
Low for differential clock mode
IFS = 32 * VREFO/RSET VREFO = 1.24 IFS = 20mA => RSET= 1.984k

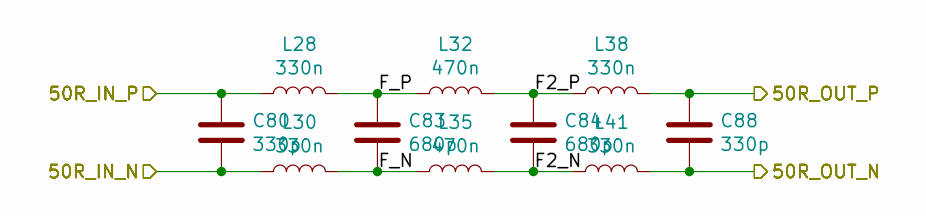
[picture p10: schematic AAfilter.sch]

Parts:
C68, C76: 330p; C_0603_1608Metric; LCSC C1664
C71, C72: 680p; C_0603_1608Metric; LCSC C30816
L10, L12, L20, L23: 330n; L_0603_1608Metric; LCSC C46859
L14, L17: 470n; L_0603_1608Metric; LCSC C21307

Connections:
/IQ DAC and AA filter/I AA Filter/50R_IN_N: C68.2, L12.1; also elsewhere on the board
/IQ DAC and AA filter/I AA Filter/50R_IN_P: C68.1, L10.1; also elsewhere on the board
/IQ DAC and AA filter/I AA Filter/50R_OUT_N: C76.2, L23.2; also elsewhere on the board
/IQ DAC and AA filter/I AA Filter/50R_OUT_P: C76.1, L20.2; also elsewhere on the board
/IQ DAC and AA filter/I AA Filter/F2_N: C72.2, L17.2, L23.1
/IQ DAC and AA filter/I AA Filter/F2_P: C72.1, L14.2, L20.1
/IQ DAC and AA filter/I AA Filter/F_N: C71.2, L12.2, L17.1
/IQ DAC and AA filter/I AA Filter/F_P: C71.1, L10.2, L14.1

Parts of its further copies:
C80, C88: 330p; C_0603_1608Metric; LCSC C1664
C83, C84: 680p; C_0603_1608Metric; LCSC C30816
L28, L30, L38, L41: 330n; L_0603_1608Metric; LCSC C46859
L32, L35: 470n; L_0603_1608Metric; LCSC C21307

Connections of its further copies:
/IQ DAC and AA filter/Q AA filter/50R_IN_N: C80.2, L30.1; also elsewhere on the board
/IQ DAC and AA filter/Q AA filter/50R_IN_P: C80.1, L28.1; also elsewhere on the board
/IQ DAC and AA filter/Q AA filter/50R_OUT_N: C88.2, L41.2; also elsewhere on the board
/IQ DAC and AA filter/Q AA filter/50R_OUT_P: C88.1, L38.2; also elsewhere on the board
/IQ DAC and AA filter/Q AA filter/F2_N: C84.2, L35.2, L41.1
/IQ DAC and AA filter/Q AA filter/F2_P: C84.1, L32.2, L38.1
/IQ DAC and AA filter/Q AA filter/F_N: C83.2, L30.2, L35.1
/IQ DAC and AA filter/Q AA filter/F_P: C83.1, L28.2, L32.1

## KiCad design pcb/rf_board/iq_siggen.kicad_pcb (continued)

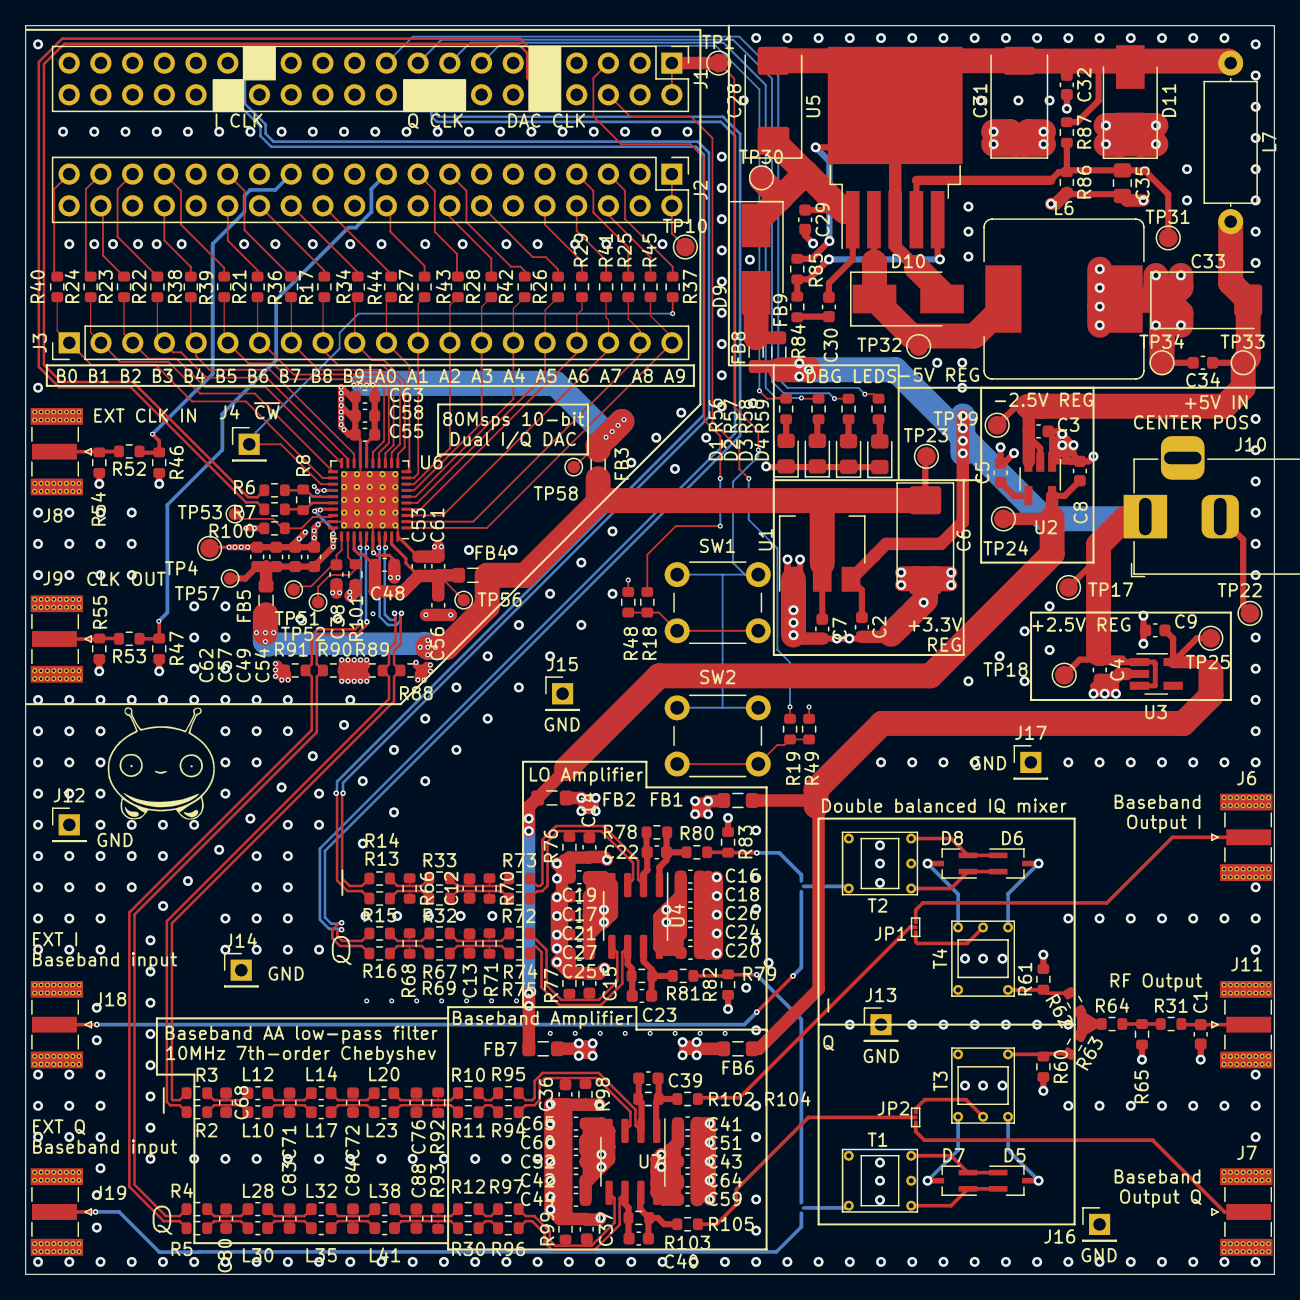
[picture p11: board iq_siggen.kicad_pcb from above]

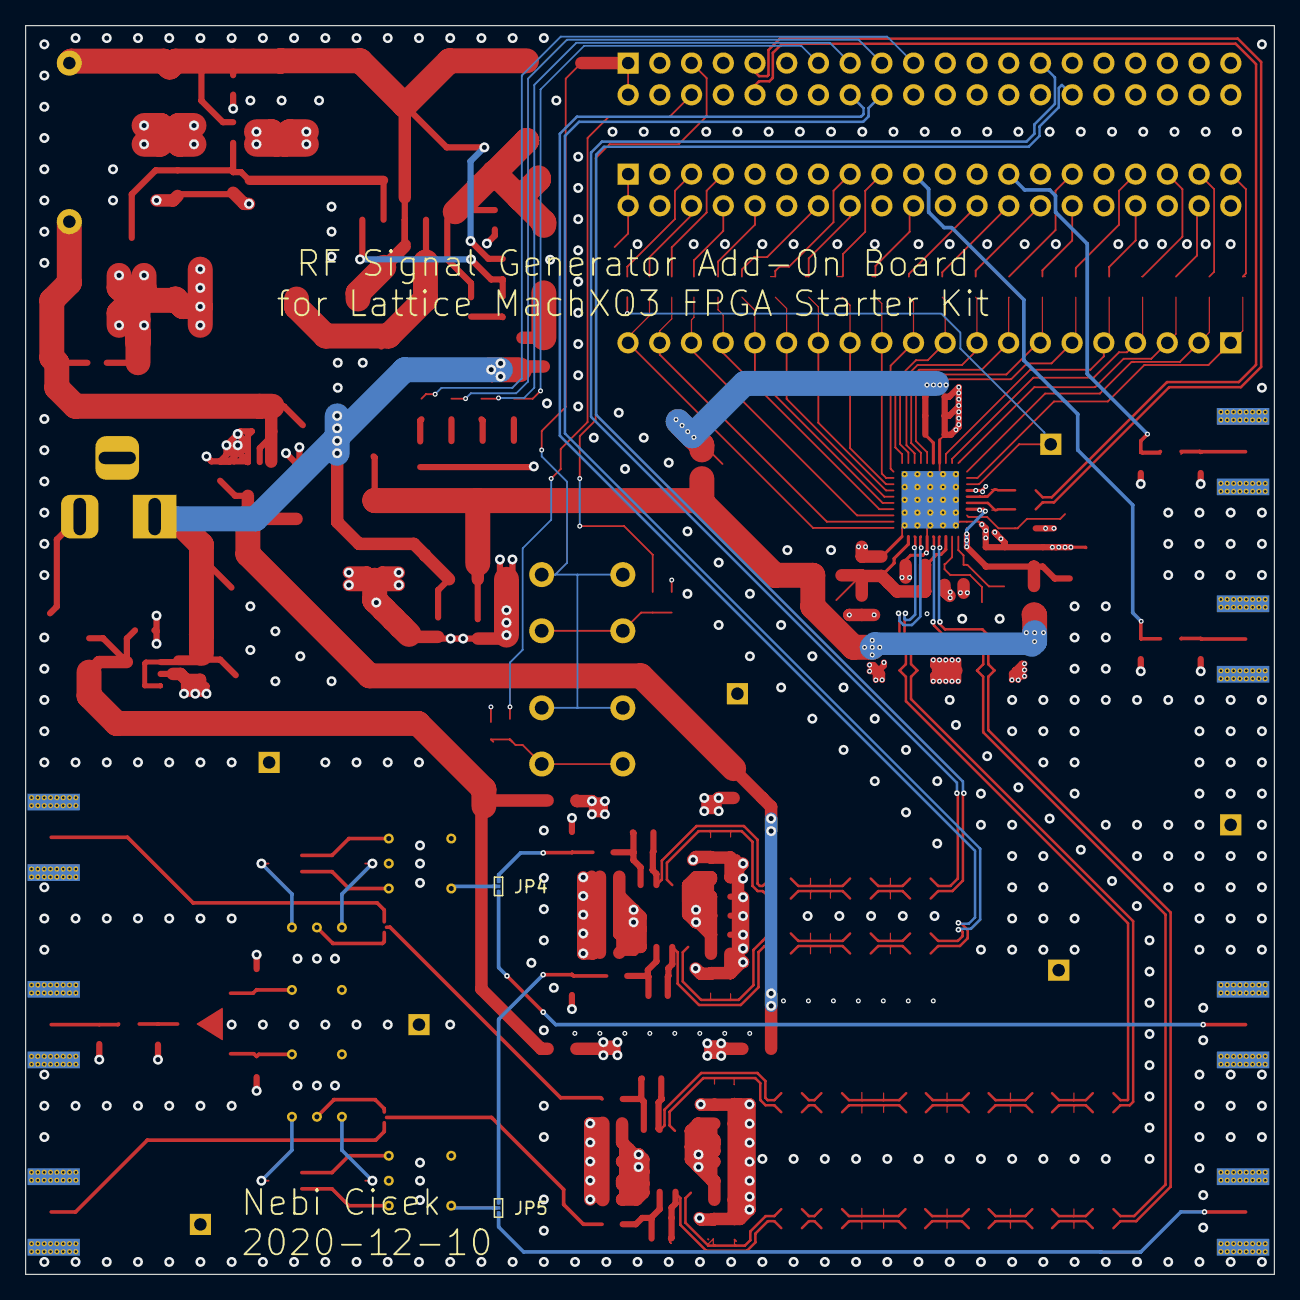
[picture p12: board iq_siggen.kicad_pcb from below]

Board: 4 copper layers, 100.0 x 100.0 mm, 256 parts (2 on the bottom side), 161 nets.

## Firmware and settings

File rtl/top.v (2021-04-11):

`default_nettype none
`timescale 1 ns / 100 ps

module top(i_ref_clk,
		// UART/host to wishbone interface
		i_wbu_uart_rx, o_wbu_uart_tx,

		//pushbuttons
		i_sw0, i_sw1,

        //signal outputs
        o_dac_a, o_dac_b,
		dac_clk_p, dac_clk_n,
		o_dac_cw_b,
		o_lo_i,
		o_lo_q
);

parameter sine_lookup_width = 16,
		phase_width = 12,
		accumulator_width = 32,
		lo_phase_width = 12,
		lo_accumulator_width = 32,
		output_dac_width = 10;
	
input wire i_ref_clk;

input wire i_wbu_uart_rx;
output wire o_wbu_uart_tx;

input wire i_sw0, i_sw1;

output wire [(output_dac_width-1):0] o_dac_a, o_dac_b;
output wire o_lo_i, o_lo_q, dac_clk_p, dac_clk_n, o_dac_cw_b;

wire reset;
assign reset = i_sw0;

`ifdef	synthesis
	PUR PUR_INST (.PUR (reset));
	GSR GSR_INST (.GSR (reset));
`endif


wire clk;
`ifdef	synthesis
	sys_clk sys_clk_inst (.CLKI(i_ref_clk), .CLKOP(clk));
`else
	assign clk = i_ref_clk;
`endif


//differential clock outputs
assign dac_clk_n = ~dac_clk_p;
assign dac_clk_p = clk;

wire rx_stb;
wire [7:0] rx_data;
`ifdef	synthesis
	rxuartlite #(.TIMER_BITS(24), .CLOCKS_PER_BAUD(10000)) rxtransport(clk, i_wbu_uart_rx, rx_stb, rx_data);
`else
	rxuartlite #(.TIMER_BITS(24), .CLOCKS_PER_BAUD(20)) rxtransport(clk, i_wbu_uart_rx, rx_stb, rx_data);
`endif

wire tx_stb, tx_busy;
wire [7:0] tx_data;
`ifdef	synthesis
	//UARTSETUP = clk / baud at 8N1. 10000 == 9600 baud @ 96MHz
	txuartlite #(.TIMING_BITS(24), .CLOCKS_PER_BAUD(10000)) txtransport(clk, tx_stb, tx_data, o_wbu_uart_tx, tx_busy);
`else
	txuartlite #(.TIMING_BITS(24), .CLOCKS_PER_BAUD(20)) txtransport(clk, tx_stb, tx_data, o_wbu_uart_tx, tx_busy);
`endif

wire wb_cyc, wb_stb, wb_we;
wire [29:0] wb_addr;
wire [31:0] wb_odata;
wire [3:0] wb_sel;
reg wb_ack;
wire wb_stall;
reg	wb_err;
reg	[31:0] wb_idata;
wire bus_interrupt;

hbbus genbus (.i_clk(clk),
	.i_rx_stb(rx_stb), 	// The receive transport wires
	.i_rx_byte(rx_data),
	.o_wb_cyc(wb_cyc), // The bus control output wires
	.o_wb_stb(wb_stb), 
	.o_wb_we(wb_we), 
	.o_wb_addr(wb_addr), 
	.o_wb_data(wb_odata), 
	.o_wb_sel(wb_sel),
	.i_wb_stall(wb_stall), //	The return bus wires
	.i_wb_ack(wb_ack), 
	.i_wb_data(wb_idata), 
	.i_wb_err(wb_err),
	.i_interrupt(bus_interrupt), // An interrupt line
	.o_tx_stb(tx_stb), // The return transport wires
	.o_tx_byte(tx_data), 
	.i_tx_busy(tx_busy));




reg [29:0] bus_err_address;
initial	bus_err_address = 0;





//SLAVES:
wire wb_fm_sel, wb_fm_stall, wb_fm_ack;
wire [31:0] wb_fm_data;

fm_generator_wb_slave #(
	.sine_lookup_width(sine_lookup_width),
	.phase_width(phase_width),
	.accumulator_width(accumulator_width),
	.output_dac_width(output_dac_width)
	)
	fm_generator_wb_instance(.i_clk(clk), .i_reset(reset), 
                            .i_wb_cyc(wb_cyc), 
                            .i_wb_stb(wb_stb && wb_fm_sel), 
                            .i_wb_we(wb_we), 
                            .i_wb_addr(wb_addr[2:0]), 
                            .i_wb_data(wb_odata),
                            .o_wb_ack(wb_fm_ack), 
                            .o_wb_stall(wb_fm_stall), 
                            .o_wb_data(wb_fm_data),
                            .o_dac_a_registered(o_dac_a),
							.o_dac_b_registered(o_dac_b),
							.o_cw_b(o_dac_cw_b)
);

wire wb_lo_sel, lo_lock, wb_lo_stall;
wire [7:0] wb_lo_data;
wire wb_lo_ack;			

assign wb_lo_stall = 1'b0;

wire pll_clk, pll_rst, pll_stb, pll_we, pll_ack;
wire [7:0] pll_data_i, pll_data_o;
wire [4:0] pll_addr;

//check wishbone spec what master strobe is supposed to do. 
//efb needs stb high until ack back. 
//zipcpu slaves did not (maybe they were pipelined mode wb and this is not...)
//thats why we connect cyc to efb's stb line.
wire wb_cyc_efb, wb_stb_efb;
`ifdef	synthesis
	assign wb_cyc_efb = wb_cyc;
	assign wb_stb_efb = wb_cyc;
`else
	assign #0.1 wb_cyc_efb = wb_cyc;
	assign #0.1 wb_stb_efb = wb_cyc;
`endif

wire lo_pll_out, lo_i, lo_q, lo_i_en, lo_q_en;
/*clock_phase_shifter clock_phase_shifter_inst(
    .i_clk_2f(lo_pll_out),
    .o_clk_i(lo_i),
    .o_clk_q(lo_q)
);*/
assign o_lo_i = lo_i & lo_i_en;
assign o_lo_q = lo_q & lo_q_en;

`ifdef	synthesis
	dynamic_pll lo_gen(.CLKI(i_ref_clk), 
			.PLLCLK(pll_clk), 
			.PLLRST(pll_rst), 
			.PLLSTB(pll_stb), 
			.PLLWE(pll_we), 
			.PLLDATI(pll_data_i), 
			.PLLADDR(pll_addr), 
			.PLLDATO(pll_data_o), 
			.PLLACK(pll_ack),
			.CLKOP(lo_i), 
			.CLKOS(lo_q),
			.LOCK(lo_lock)
			);

	efb_inst efb_inst_0 (
		.wb_clk_i(clk), 
		.wb_rst_i(reset), 
		.wb_cyc_i(wb_cyc_efb), 
		.wb_stb_i(wb_stb_efb && wb_lo_sel), 
		.wb_we_i(wb_we), 
		.wb_adr_i(wb_addr[7:0]), 
		.wb_dat_i(wb_odata[7:0]), 
		.wb_dat_o(wb_lo_data), 
		.wb_ack_o(wb_lo_ack), 
		.pll0_bus_i({pll_data_o, pll_ack}), 
		.pll0_bus_o({pll_clk, pll_rst, pll_stb, pll_we, pll_addr, pll_data_i})
		);
`else
	assign lo_pll_out = i_ref_clk;
`endif



wire wb_control_sel, wb_control_ack, wb_control_stall;
wire [31:0] wb_control_data;
control control_inst(	.i_clk(clk), 
						.i_reset(reset), 
						.i_wb_cyc(wb_cyc), 
						.i_wb_stb(wb_stb && wb_control_sel), 
						.i_wb_we(wb_we), 
						.i_wb_addr(wb_addr[2:0]), 
						.i_wb_data(wb_odata),
						.o_wb_ack(wb_control_ack), 
						.o_wb_stall(wb_control_stall), 
						.o_wb_data(wb_control_data),
						.o_lo_i_en(lo_i_en),
						.o_lo_q_en(lo_q_en)
);



//BUS plumbing
// Nothing should be assigned to the null page
assign	wb_control_sel = (wb_addr[29:8] == 22'h081);	// 0x00002040
assign	wb_fm_sel = (wb_addr[29:8] == 22'h082);	// 0x00002080
assign	wb_lo_sel = (wb_addr[29:8] == 22'h083);	// 0x000020C0

// This will be true if nothing is selected
wire none_sel;
assign none_sel = ((!wb_fm_sel) && (!wb_control_sel) && (!wb_lo_sel));

// The wishbone error signal is true for one clock only, and then it
// resets itself
always @(posedge clk)
	wb_err <= (wb_stb)&&(none_sel);


always @(posedge clk)
	if (wb_err)
		bus_err_address <= wb_addr;

assign wb_stall = ((wb_fm_sel)&&(wb_fm_stall))||((wb_control_sel)&&(wb_control_stall))||((wb_lo_sel)&&(wb_lo_stall));

initial	wb_ack = 1'b0;
always @(posedge clk)
	wb_ack <= (wb_fm_ack) || (wb_control_ack) || (wb_lo_ack);

always @(posedge clk)
	if (wb_fm_ack)
		wb_idata <= wb_fm_data;
	else if (wb_control_ack)
		wb_idata <= wb_control_data;
	else if (wb_lo_ack)
		wb_idata <= {24'b0, wb_lo_data};
	else
		wb_idata <= 32'bxxxxxxxxxxxxxxxxxxxxxxxxxxxxxxxx;

assign bus_interrupt = 1'b0;


endmodule
`default_nettype wire

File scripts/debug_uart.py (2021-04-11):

import serial
import math 

class Device():
    def __init__(self, ser):
        self.ser = ser

    def read(self, addr):
        tx = "A"+format(addr<<2, 'x')+'\n'
        self.ser.write(tx.encode())
        self.ser.readline()
        tx = "R"+'\n'
        self.ser.write(tx.encode())
        rx = self.ser.readline().decode().rstrip().split('R')[1]
        value = int(rx,16)
        print("read ", hex(value), " from ", hex(addr))
        return value

    def write(self, addr, data):
        assert data <= 0xFFFFFFFF
        tx = "A"+format(addr<<2, 'x').lower()+'\n'
        self.ser.write(tx.encode())
        self.ser.readline()
        tx = "W"+format(data, 'x').lower()+'\n'
        self.ser.write(tx.encode())
        print("wrote ", hex(data), " to ", hex(addr))

    def set_modulation_amount(self, val):
        #assert val < 100
        self.write(((0x82<<8)+2), val)

    def set_modulation_frequency(self, hz):
        count = 2**32*hz/refclk
        assert count < 2**32
        self.write(((0x82<<8)+1), int(round(count)))

    def set_carrier_frequency(self, hz):
        count = 2**32*hz/refclk
        assert count < 2**32
        self.write(((0x82<<8)+0), int(round(count)))

    def set_lo_frequency(self, hz):
        self.write(((0x83<<8)+0), int(round(count)))

    def set_i_gain(self, val):
        self.write(((0x82<<8)+3), int(round(val)))

    def set_q_gain(self, val):
        self.write(((0x82<<8)+4), int(round(val)))

    def set_lo_i(self, enable):
        assert isinstance(enable, bool)
        read = self.read((0x81<<8)+0)
        read &= ~(1<<0)
        read |= int(enable)<<0
        self.write(((0x81<<8)+0), read)

    def set_lo_q(self, enable):
        assert isinstance(enable, bool)
        read = self.read((0x81<<8)+0)
        read &= ~(1<<1)
        read |= int(enable)<<1
        self.write(((0x81<<8)+0), read)

class EFB_PLL():
    def __init__(self, dev, efb_wishbone_base_address, ref_clk):
        self.dev = dev
        self.base_address = efb_wishbone_base_address
        self.ref_clk = ref_clk

    def set_fb_div(self, div):
        int_div = int(math.floor(div))
        frac_div = int(round((div - int_div) * 65535))
        assert frac_div <= 65535
        assert int_div <= 127
        
        print(int_div, frac_div)
        self.dev.write(self.base_address + 6, int_div-1) #MC1_DIVA
        
        #CLKOP section Delay value for coarse phase adjustments. For zero delay this value should be equal to the value of MC1_DIVA[6:0].
        #self.dev.write(self.base_address + 2, int_div-1) #MC1_DELA 
        
        self.dev.write(self.base_address + 0, frac_div&0b11111111) #MC1_DIVFBK_FRAC
        self.dev.write(self.base_address + 1, (frac_div>>8)&0b11111111) 
        self.dev.write(self.base_address + 5, 1<<7) #MC1_USE_DESI


ser = serial.Serial('COM8', 7200)  # open serial port
refclk = 12e6

dev = Device(ser)
dev.set_lo_q(False)
efb_pll = EFB_PLL(dev, 0x83<<8, refclk)
efb_pll.set_fb_div(2.00)

dev.set_carrier_frequency(1e6)
dev.set_modulation_frequency(1e3)
dev.set_modulation_amount(0)

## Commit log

2020-09-27 uart comms script now working
2020-11-14 Add PCB
    [MC33063ADR.step, TLV73325PDBVT.step, TPS6735ID.step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]
2020-11-14 clean up
    [MC33063ADR.step, TPS6735ID.step, neg_rail_gen.sch]
2020-11-14 sims and dco spectral purity analysis
    [wave.csv]
2020-11-17 Define pin map, clean up schematic
    [AAfilter.sch, FPGA-board pinmap.xlsx, dac.sch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]
2020-11-17 kicad junk in gitignore
2020-11-18 clean up ERC, more DFT stuff, started sigma delta adc
    [AAfilter.sch, FPGA-board pinmap.xlsx, dac.sch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]
2020-11-18 add ext LO connectors, more decoupling
    [dac.sch, mixer.sch]
2020-11-19 started assigning footprints
    [AAfilter.sch, dac.sch, iq_siggen.sch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]
2020-11-20 add schematic libs
2020-11-20 Update footprints, move to 0603 passives for JLCPCB assembly, create transformer footprints
    [AAfilter.sch, dac.sch, iq_siggen.sch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]
2020-11-21 add design rules, import parts
    [iq_siggen.kicad_pcb]
2020-11-21 routing mixer
    [iq_siggen.kicad_pcb, mixer.sch]
2020-11-21 lined up data bus resistors, done 5v reg, started the -5V switching regulator
    [iq_siggen.kicad_pcb, mixer.sch]
2020-11-22 finish up vregs, routed filters, iq baseband outputs
    [AAfilter.sch, dac.sch, iq_siggen.kicad_pcb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]
2020-11-23 layout progress
    [dac.sch, iq_siggen.kicad_pcb, iq_siggen.sch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]
2020-11-25 Add SMA step model
    [SMA-J-P-H-ST-EM1--3DModel-STEP-46669.STEP, iq_siggen.sch, mixer.sch]
2020-11-25 route A and B channels on input connector
    [iq_siggen.kicad_pcb, iq_siggen.sch]
2020-11-26 LO amp routing
    [dac.sch, iq_siggen.kicad_pcb, iq_siggen.sch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]
2020-11-27 clean up LO driver routing
    [dac.sch, iq_siggen.kicad_pcb, iq_siggen.sch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]
2020-11-28 clean up baseband amplifier routing, make it like the LO amp
    [dac.sch, iq_siggen.kicad_pcb]
2020-11-28 route power for amplifiers, fill zones for gnd and amplifiers
    [iq_siggen.kicad_pcb, iq_siggen.sch]
2020-11-28 routing the dac wires
    [AAfilter.sch, dac.sch, iq_siggen.kicad_pcb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]
2020-11-30 laying out split gnd pours
    [dac.sch, iq_siggen.kicad_pcb, iq_siggen.sch]
2020-12-02 routing contiued, add swtiches, remove test points, all parts now positioned on board
    [AAfilter.sch, dac.sch, iq_siggen.kicad_pcb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]
2020-12-05 layout refininements, stitching vias
    [dac.sch, iq_siggen.kicad_pcb, iq_siggen.sch]
2020-12-06 clean up designators on silkscreen, label connectors and circuit blocks
    [iq_siggen.kicad_pcb]
2020-12-10 clean up, label sub circuit blocks in silkscreen document the expected clock and baseband amplitudes based on opamp gains
    [AAfilter.sch, FPGA-board pinmap.xlsx, dac.sch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]
2020-12-10 update the solder jumper clearance
    [iq_siggen.kicad_pcb]
2020-12-11 populate LCSC BOM for JLCPCB assembly
    [AAfilter.sch, dac.sch, iq_siggen.kicad_pcb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]
2020-12-11 add second parallel ferrite bead for input of negative 5V generator
    [iq_siggen.kicad_pcb, neg_rail_gen.sch]
2020-12-11 fill out more components in BOM with LCSC parts
    [iq_siggen.kicad_pcb, iq_siggen.sch, neg_rail_gen.sch]
2020-12-11 final touches
    [iq_siggen.kicad_pcb]
2020-12-11 add output gerbers
    [bom_iq_siggen.csv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]
2020-12-11 add multisim filter simulation
2020-12-25 Move rf board into it's own folder
    [AAfilter.sch, FPGA-board pinmap.xlsx, SMA-J-P-H-ST-EM1--3DModel-STEP-46669.STEP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]
2020-12-25 Sigma delta adc PCB initial commit
    [sigma_delta_adc_board.kicad_pcb, sigma_delta_adc_board.sch]
2020-12-26 finish the board
    [sigma_delta_adc_board.kicad_pcb, sigma_delta_adc_board.sch]
2021-02-03 update rc network values after tuning
    [sigma_delta_adc_board.sch]
2021-02-07 switch to verilator
2021-02-07 fix dac config mode bug, ignore some linter warnings
    [top.v]
2021-02-07 add delay to cw pin to meet timing for dac latch
2021-02-07 switch to multiplier for modulation amount scaling
2021-02-08 update uart script
2021-02-08 update tb reset button
2021-02-10 fix up the modulation multiplier, register outputs to dac
    [top.v]
